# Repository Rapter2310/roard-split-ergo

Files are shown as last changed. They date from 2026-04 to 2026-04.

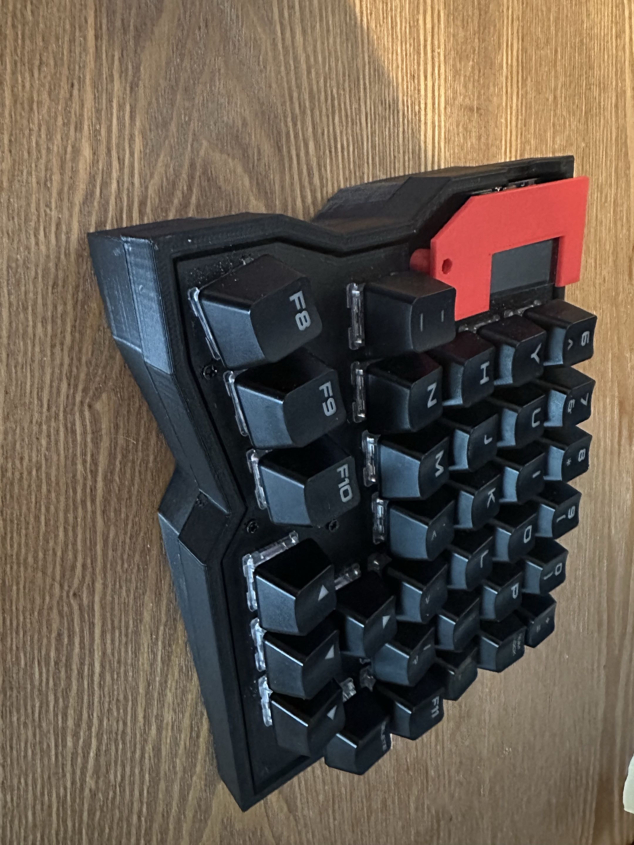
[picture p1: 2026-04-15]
docs/images/right_angle.jpg

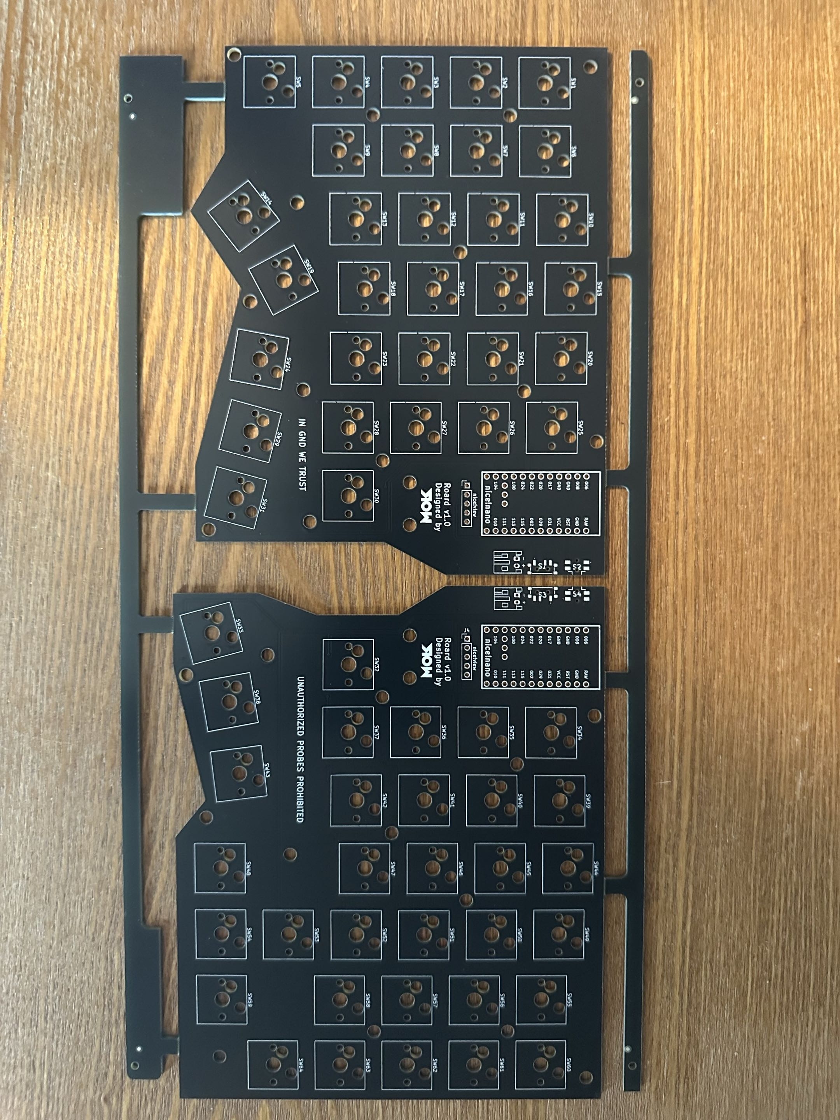
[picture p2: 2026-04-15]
docs/images/pcb_top.jpg

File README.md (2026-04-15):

# Roard Keyboard

Roard is a custom wireless split keyboard I designed, heavily based on the Lily58. The main physical difference is the layout. I modified it to include a dedicated arrow key cluster on the right half. 

The biggest technical difference is the wireless setup. Instead of standard Bluetooth, I'm using a 3-node Nordic Enhanced ShockBurst (ESB) configuration. The left and right halves connect to a third nice!nano plugged into the PC acting as a dedicated dongle, which fixes the latency and connection drops you sometimes get with standard BLE splits.

## Hardware Details
* **Controllers:** 3x nice!nano v2 (left, right, and central dongle).
* **Displays:** 2x nice!view screens.
* **Switches & Sockets:** Gateron Aliaz (silent tactiles) seated in Kailh MX hotswap sockets.
* **Power:** 3.7v 110mAh LiPo batteries.
* **Components & Assembly:** Sourced all the board-level SMD components (diodes, power/reset switches, battery connectors, and sockets) directly from Typeractive, and assembled the board using Kester solder wire.
* **Design Tools:** The core layout was built in Keyboard Layout Editor (KLE). I initially used the ai03 plate generator for rapid prototyping to test different angles and ergonomics before committing to the board design. To map the final physical matrix to the firmware, I used the [ZMK Physical Layout Converter](https://zmk-physical-layout-converter.streamlit.app/) to translate the KLE JSON directly into ZMK layout macros. The raw design files are in the `/design` folder.
* **PCB:** Custom routed in KiCad. Once the routing and standoff placements were finalized, I exported the board as a STEP file to serve as the foundation for the mechanical design.

## Case & Mechanical
I modeled the enclosure from scratch in Onshape. To guarantee perfect switch alignment and mounting hole clearance, I imported the KiCad STEP file directly into my Onshape workspace and traced the final switch plates and case standoffs around the exact geometry of the PCB.

I used a few different materials for the 3D printed parts depending on what they needed to do:
* **Case & Switch Plate:** PETG for general strength.
* **Tenting Kit:** TPU so it actually grips the desk and dampens the sound a bit.
* **Display Covers:** PLA to protect the nice!view screens.
Everything is held together with standard brass standoffs.

## Current Status & WIP
The board is fully functional as my daily driver, but I'm currently working on two main things:

1. **Customizing the nice!view Screens:** Switching from standard BLE to the ESB dongle setup breaks the standard `nice!view` widget implementation, which relies on BLE Zephyr services to report full connection states. Currently, the screens are running a basic fallback ZMK display profile that only outputs battery levels. I am actively rewriting the display logic to pull layer information and connection states over the ESB protocol to restore full functionality.
2. **Custom Keycaps:** I'm in the process of generating and 3D printing a custom keycap profile using [PseudoMakeMeKeyCapProfiles](https://github.com/pseudoku/PseudoMakeMeKeyCapProfiles).

## Repository Structure
* `/design`: KLE json files and prototyping assets.
* `/docs`: Photos of the finished board, the PCB, and the tenting kit.
* `/firmware`: ZMK config files, custom shield definitions, and ESB dongle setup.
* `/hardware`: KiCad project files, schematics, and production-ready Gerbers.
* `/mechanical`: STLs for 3D printing and STEP files exported from Onshape.

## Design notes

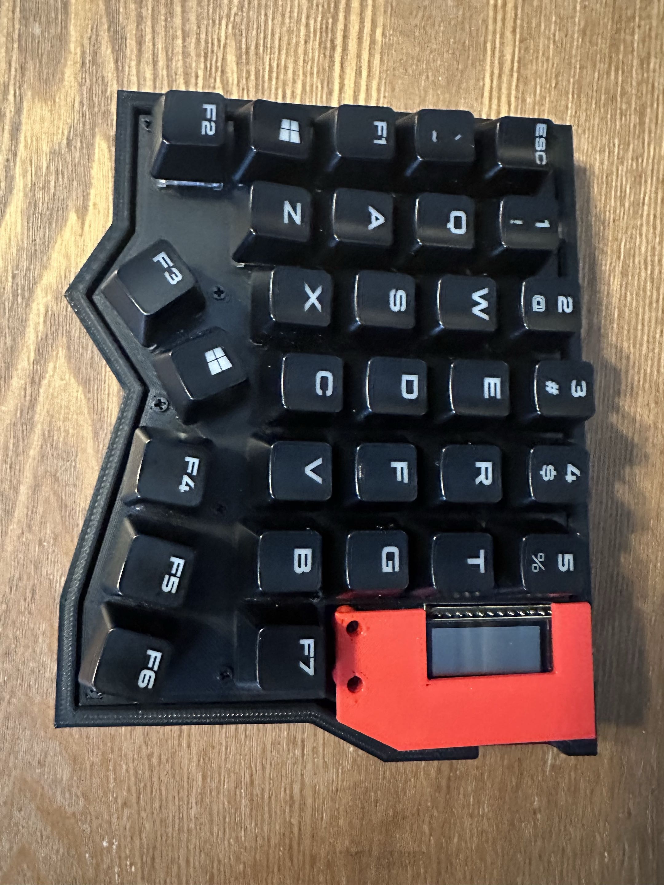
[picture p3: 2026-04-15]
docs/images/left_top.jpg

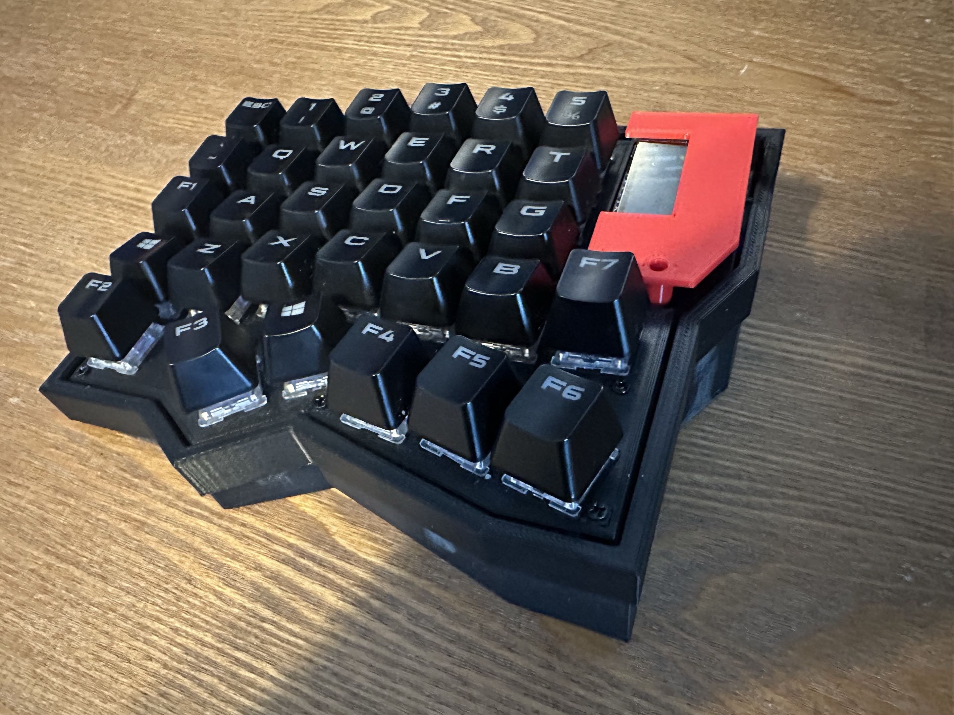
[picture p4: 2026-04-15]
docs/images/left_angle.jpg

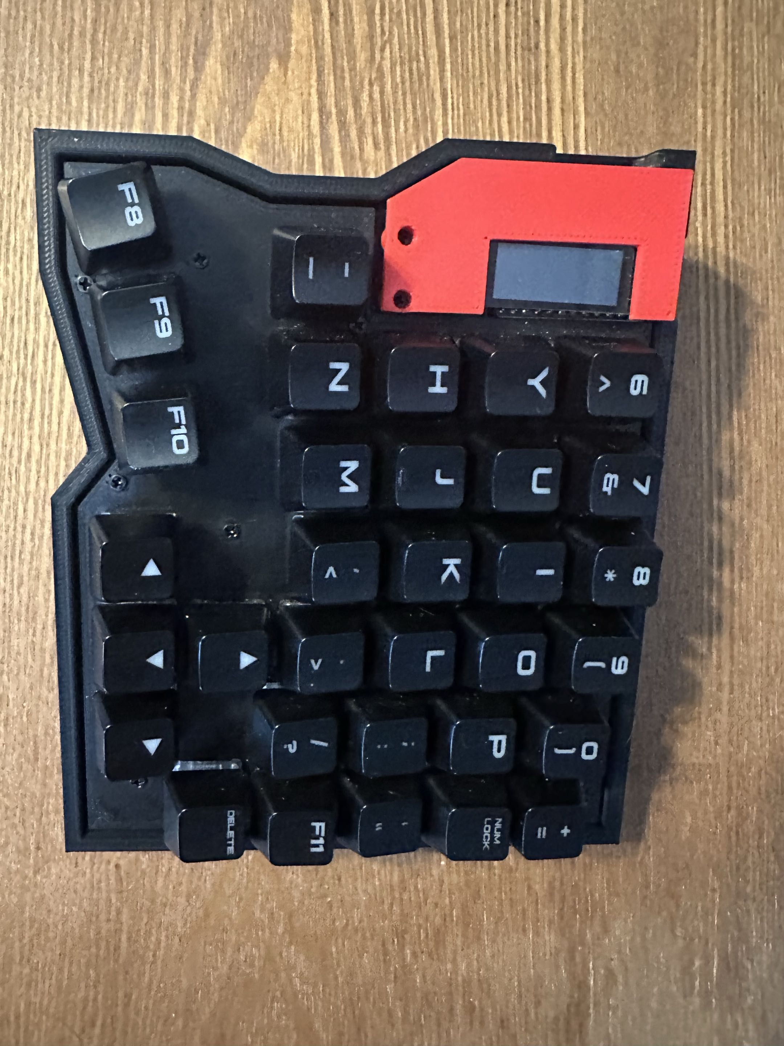
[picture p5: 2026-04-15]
docs/images/right_top.jpg

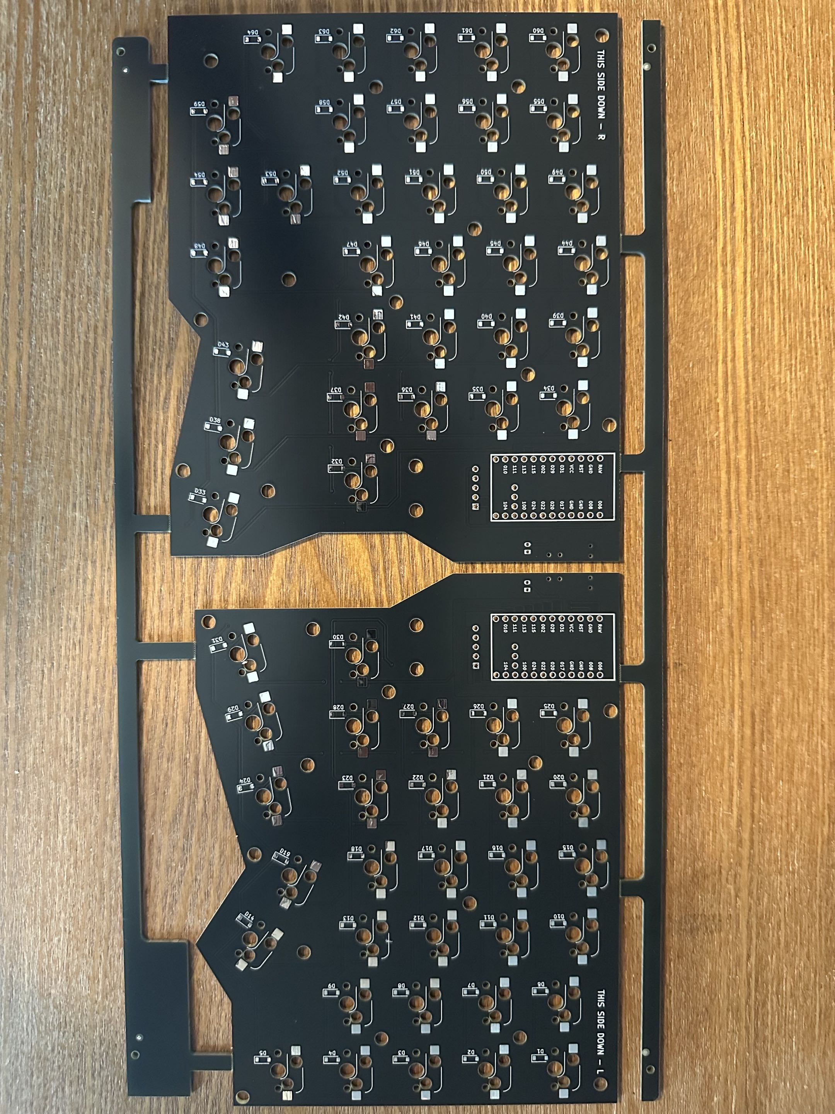
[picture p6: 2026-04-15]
docs/images/pcb_bottom.jpg

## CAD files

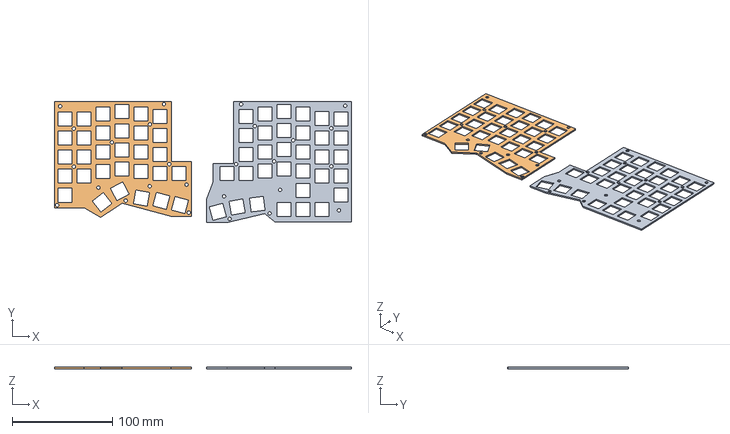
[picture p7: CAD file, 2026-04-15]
mechanical/step/plates.step
296.7 x 121.1 x 1.51 mm
plate_PCB_1
plate_PCB_2

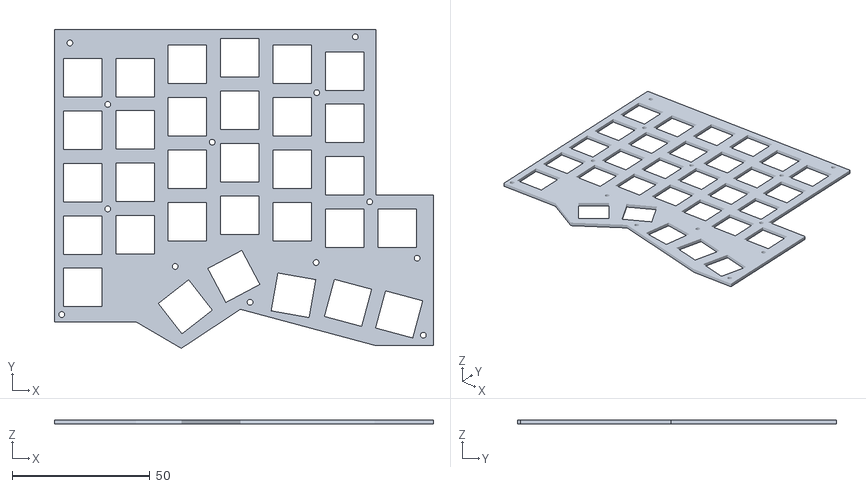
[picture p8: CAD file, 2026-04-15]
mechanical/stl/left_plate.stl
137.8 x 115.9 x 1.60

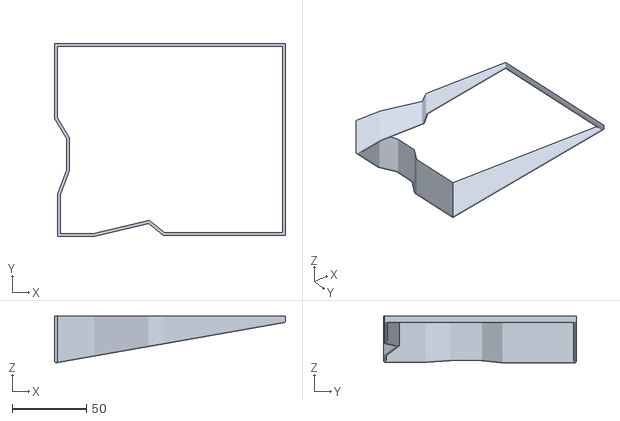
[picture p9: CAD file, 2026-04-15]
mechanical/stl/right_tent.stl
155.1 x 129.4 x 31.4

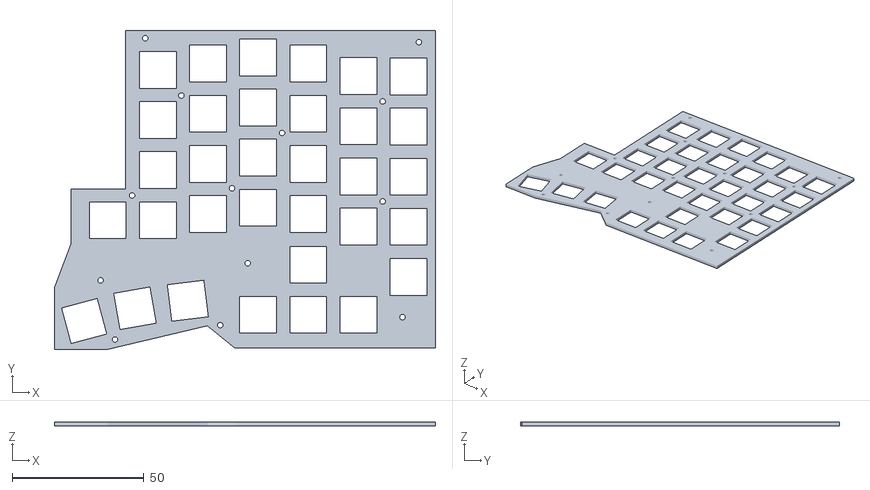
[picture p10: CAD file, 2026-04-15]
mechanical/stl/right_plate.stl
144.8 x 121.1 x 1.60

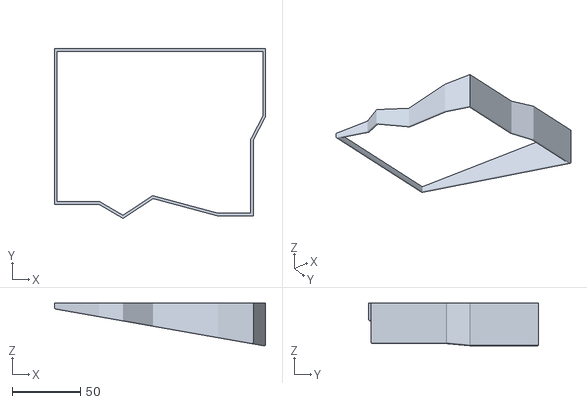
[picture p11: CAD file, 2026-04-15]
mechanical/stl/left_tent.stl
155.1 x 124.9 x 31.4

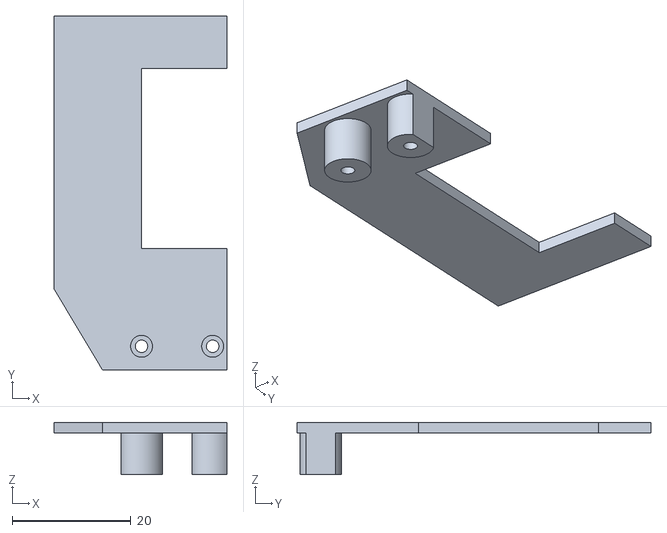
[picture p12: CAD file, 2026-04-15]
mechanical/stl/right_screen_cover.stl
29.2 x 59.7 x 8.80

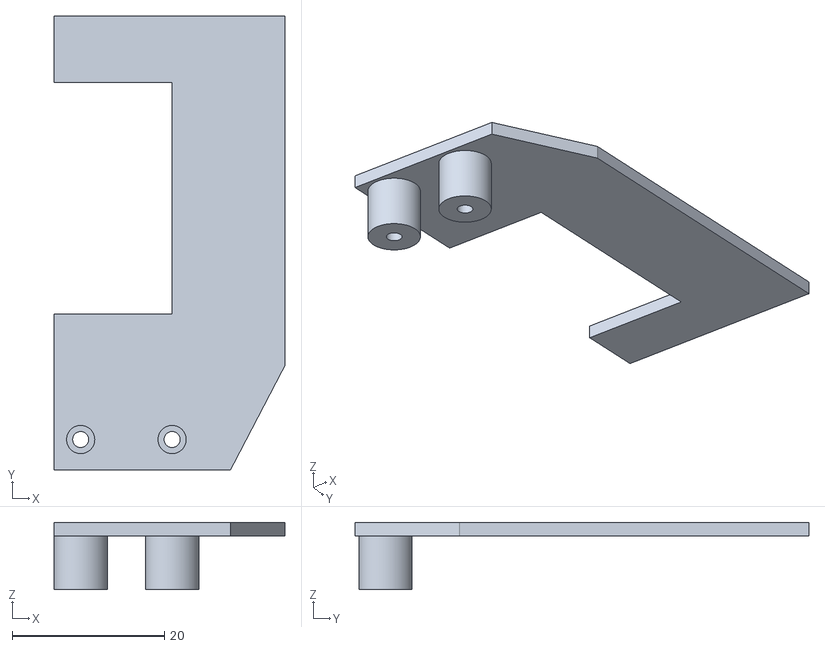
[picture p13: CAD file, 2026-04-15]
mechanical/stl/left_screen_cover.stl
30.3 x 59.6 x 8.80

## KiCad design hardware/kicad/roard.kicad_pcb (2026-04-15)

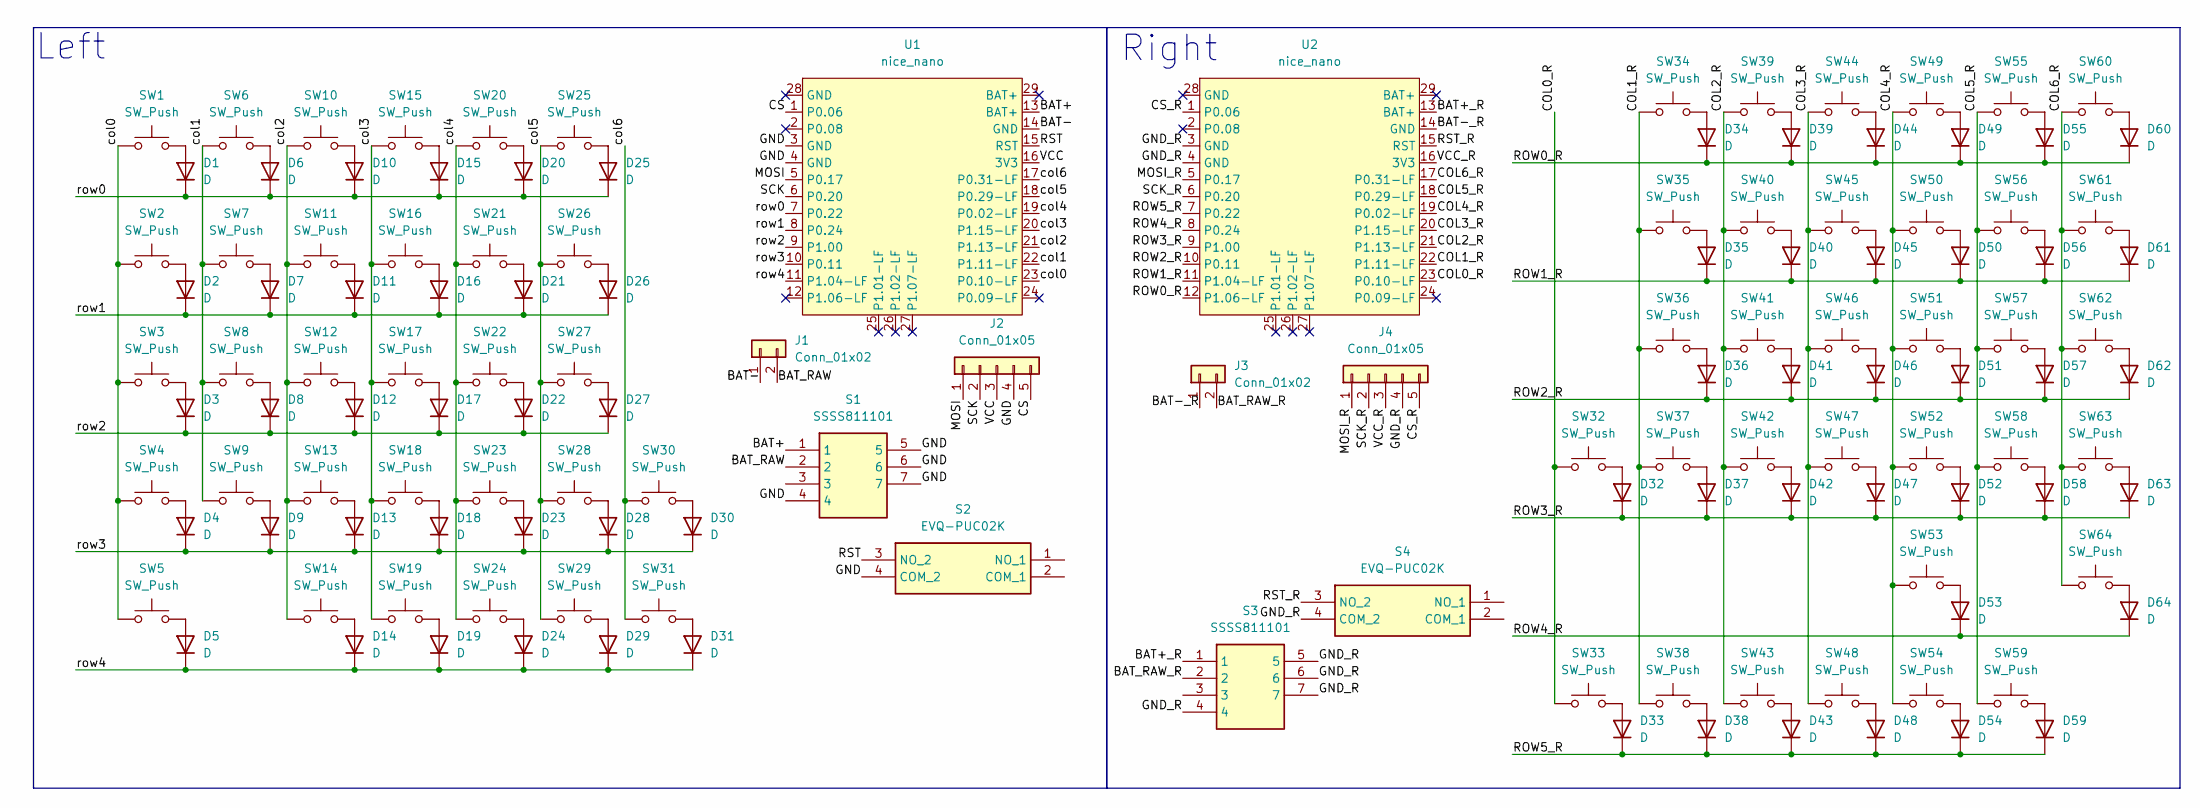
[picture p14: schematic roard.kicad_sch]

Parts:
D1, D2, D3, D4, D5, D6, D7, D8, D9, D10, D11, D12, D13, D14, D15, D16, D17, D18, D19, D20, D21, D22, D23, D24, D25, D26, D27, D28, D29, D30, D31, D32, D33, D34, D35, D36, D37, D38, D39, D40, D41, D42, D43, D44, D45, D46, D47, D48, D49, D50, D51, D52, D53, D54, D55, D56, D57, D58, D59, D60, D61, D62, D63, D64: D; D_SOD-123
J1, J3: Conn_01x02; JST_PH_S2B-PH-K_1x02_P2.00mm_Horizontal
J2, J4: Conn_01x05; PinHeader_1x05_P2.54mm_Vertical
S1, S3: SSSS811101; Mouser Part Number 688-SSSS811101
S2, S4: EVQ-PUC02K; EVQPUC02K; Mouser Part Number 667-EVQ-PUC02K
SW1, SW2, SW3, SW4, SW5, SW6, SW7, SW8, SW9, SW10, SW11, SW12, SW13, SW14, SW15, SW16, SW17, SW18, SW19, SW20, SW21, SW22, SW23, SW24, SW25, SW26, SW27, SW28, SW29, SW30, SW31, SW32, SW33, SW34, SW35, SW36, SW37, SW38, SW39, SW40, SW41, SW42, SW43, SW44, SW45, SW46, SW47, SW48, SW49, SW50, SW51, SW52, SW53, SW54, SW55, SW56, SW57, SW58, SW59, SW60, SW61, SW62, SW63, SW64: SW_Push; SW_Hotswap_Kailh_MX
U1, U2: nice_nano; nice_nano_pinChange

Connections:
/BAT+: S1.1, U1.13 (BAT+)
/BAT+_R: S3.1, U2.13 (BAT+)
/BAT-: J1.1, U1.14 (GND)
/BAT-_R: J3.1, U2.14 (GND)
/BAT_RAW: J1.2, S1.2
/BAT_RAW_R: J3.2, S3.2
/COL0_R: SW32.1, SW33.1, U2.23 (P0.10-LF)
/COL1_R: SW34.1, SW35.1, SW36.1, SW37.1, SW38.1, U2.22 (P1.11-LF)
/COL2_R: SW39.1, SW40.1, SW41.1, SW42.1, SW43.1, U2.21 (P1.13-LF)
/COL3_R: SW44.1, SW45.1, SW46.1, SW47.1, SW48.1, U2.20 (P1.15-LF)
/COL4_R: SW49.1, SW50.1, SW51.1, SW52.1, SW53.1, SW54.1, U2.19 (P0.02-LF)
/COL5_R: SW55.1, SW56.1, SW57.1, SW58.1, SW59.1, U2.18 (P0.29-LF)
/COL6_R: SW60.1, SW61.1, SW62.1, SW63.1, SW64.1, U2.17 (P0.31-LF)
/CS: J2.5, U1.1 (P0.06)
/CS_R: J4.5, U2.1 (P0.06)
/GND: J2.4, S1.4, S1.5, S1.6, S1.7, S2.4 (COM_2), U1.3 (GND), U1.4 (GND)
/GND_R: J4.4, S3.4, S3.5, S3.6, S3.7, S4.4 (COM_2), U2.3 (GND), U2.4 (GND)
/MOSI: J2.1, U1.5 (P0.17)
/MOSI_R: J4.1, U2.5 (P0.17)
/ROW0_R: D34.1 (K), D39.1 (K), D44.1 (K), D49.1 (K), D55.1 (K), D60.1 (K), U2.12 (P1.06-LF)
/ROW1_R: D35.1 (K), D40.1 (K), D45.1 (K), D50.1 (K), D56.1 (K), D61.1 (K), U2.11 (P1.04-LF)
/ROW2_R: D36.1 (K), D41.1 (K), D46.1 (K), D51.1 (K), D57.1 (K), D62.1 (K), U2.10 (P0.11)
/ROW3_R: D32.1 (K), D37.1 (K), D42.1 (K), D47.1 (K), D52.1 (K), D58.1 (K), D63.1 (K), U2.9 (P1.00)
/ROW4_R: D53.1 (K), D64.1 (K), U2.8 (P0.24)
/ROW5_R: D33.1 (K), D38.1 (K), D43.1 (K), D48.1 (K), D54.1 (K), D59.1 (K), U2.7 (P0.22)
/RST: S2.3 (NO_2), U1.15 (RST)
/RST_R: S4.3 (NO_2), U2.15 (RST)
/SCK: J2.2, U1.6 (P0.20)
/SCK_R: J4.2, U2.6 (P0.20)
/VCC: J2.3, U1.16 (3V3)
/VCC_R: J4.3, U2.16 (3V3)
/col0: SW1.1, SW2.1, SW3.1, SW4.1, SW5.1, U1.23 (P0.10-LF)
/col1: SW6.1, SW7.1, SW8.1, SW9.1, U1.22 (P1.11-LF)
/col2: SW10.1, SW11.1, SW12.1, SW13.1, SW14.1, U1.21 (P1.13-LF)
/col3: SW15.1, SW16.1, SW17.1, SW18.1, SW19.1, U1.20 (P1.15-LF)
/col4: SW20.1, SW21.1, SW22.1, SW23.1, SW24.1, U1.19 (P0.02-LF)
/col5: SW25.1, SW26.1, SW27.1, SW28.1, SW29.1, U1.18 (P0.29-LF)
/col6: SW30.1, SW31.1, U1.17 (P0.31-LF)
/row0: D1.1 (K), D6.1 (K), D10.1 (K), D15.1 (K), D20.1 (K), D25.1 (K), U1.7 (P0.22)
/row1: D2.1 (K), D7.1 (K), D11.1 (K), D16.1 (K), D21.1 (K), D26.1 (K), U1.8 (P0.24)
/row2: D3.1 (K), D8.1 (K), D12.1 (K), D17.1 (K), D22.1 (K), D27.1 (K), U1.9 (P1.00)
/row3: D4.1 (K), D9.1 (K), D13.1 (K), D18.1 (K), D23.1 (K), D28.1 (K), D30.1 (K), U1.10 (P0.11)
/row4: D5.1 (K), D14.1 (K), D19.1 (K), D24.1 (K), D29.1 (K), D31.1 (K), U1.11 (P1.04-LF)
unnamed: D1.2 (A), SW1.2
unnamed: D2.2 (A), SW2.2
unnamed: D3.2 (A), SW3.2
unnamed: D4.2 (A), SW4.2
unnamed: D5.2 (A), SW5.2
unnamed: D6.2 (A), SW6.2
unnamed: D7.2 (A), SW7.2
unnamed: D8.2 (A), SW8.2
unnamed: D9.2 (A), SW9.2
unnamed: D10.2 (A), SW10.2
unnamed: D11.2 (A), SW11.2
unnamed: D12.2 (A), SW12.2
unnamed: D13.2 (A), SW13.2
unnamed: D14.2 (A), SW14.2
unnamed: D15.2 (A), SW15.2
unnamed: D16.2 (A), SW16.2
unnamed: D17.2 (A), SW17.2
unnamed: D18.2 (A), SW18.2
unnamed: D19.2 (A), SW19.2
unnamed: D20.2 (A), SW20.2
unnamed: D21.2 (A), SW21.2
unnamed: D22.2 (A), SW22.2
unnamed: D23.2 (A), SW23.2
unnamed: D24.2 (A), SW24.2
unnamed: D25.2 (A), SW25.2
unnamed: D26.2 (A), SW26.2
unnamed: D27.2 (A), SW27.2
unnamed: D28.2 (A), SW28.2
unnamed: D29.2 (A), SW29.2
unnamed: D30.2 (A), SW30.2
unnamed: D31.2 (A), SW31.2
unnamed: D32.2 (A), SW32.2
unnamed: D33.2 (A), SW33.2
unnamed: D34.2 (A), SW34.2
unnamed: D35.2 (A), SW35.2
unnamed: D36.2 (A), SW36.2
unnamed: D37.2 (A), SW37.2
unnamed: D38.2 (A), SW38.2
unnamed: D39.2 (A), SW39.2
unnamed: D40.2 (A), SW40.2
unnamed: D41.2 (A), SW41.2
unnamed: D42.2 (A), SW42.2
unnamed: D43.2 (A), SW43.2
unnamed: D44.2 (A), SW44.2
unnamed: D45.2 (A), SW45.2
unnamed: D46.2 (A), SW46.2
unnamed: D47.2 (A), SW47.2
unnamed: D48.2 (A), SW48.2
unnamed: D49.2 (A), SW49.2
unnamed: D50.2 (A), SW50.2
unnamed: D51.2 (A), SW51.2
unnamed: D52.2 (A), SW52.2
unnamed: D53.2 (A), SW53.2
unnamed: D54.2 (A), SW54.2
unnamed: D55.2 (A), SW55.2
unnamed: D56.2 (A), SW56.2
unnamed: D57.2 (A), SW57.2
unnamed: D58.2 (A), SW58.2
unnamed: D59.2 (A), SW59.2
unnamed: D60.2 (A), SW60.2
unnamed: D61.2 (A), SW61.2
unnamed: D62.2 (A), SW62.2
unnamed: D63.2 (A), SW63.2
unnamed: D64.2 (A), SW64.2

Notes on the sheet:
Right
Left

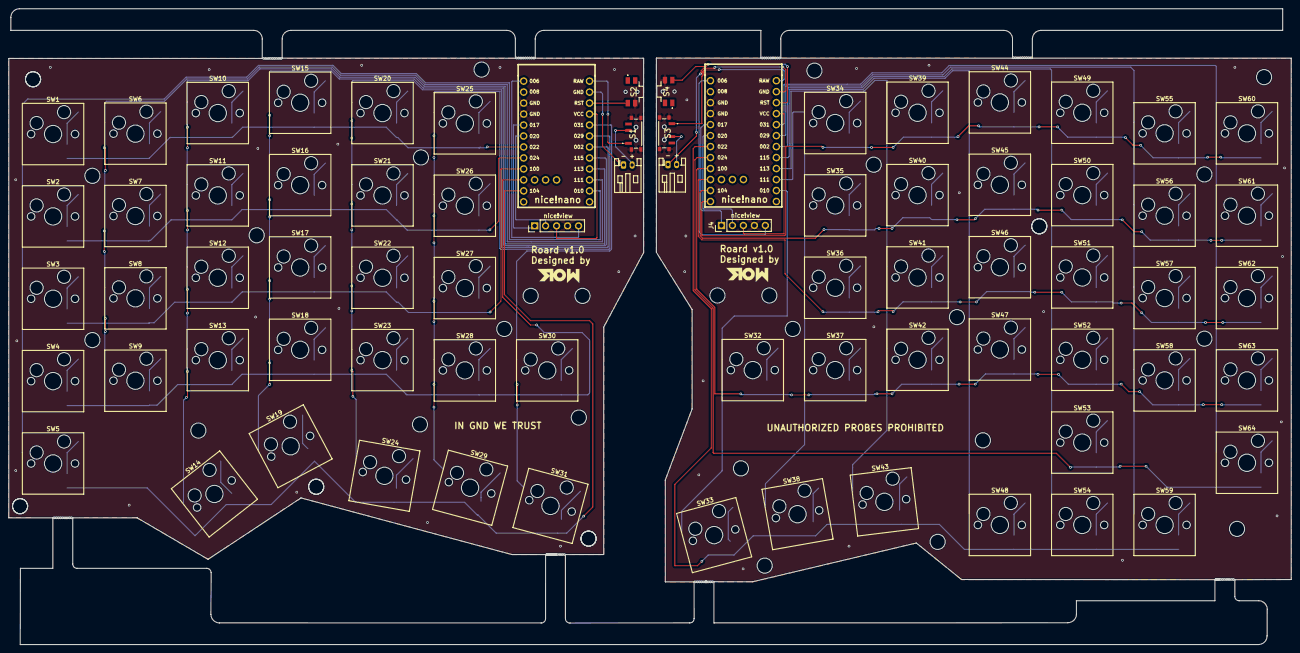
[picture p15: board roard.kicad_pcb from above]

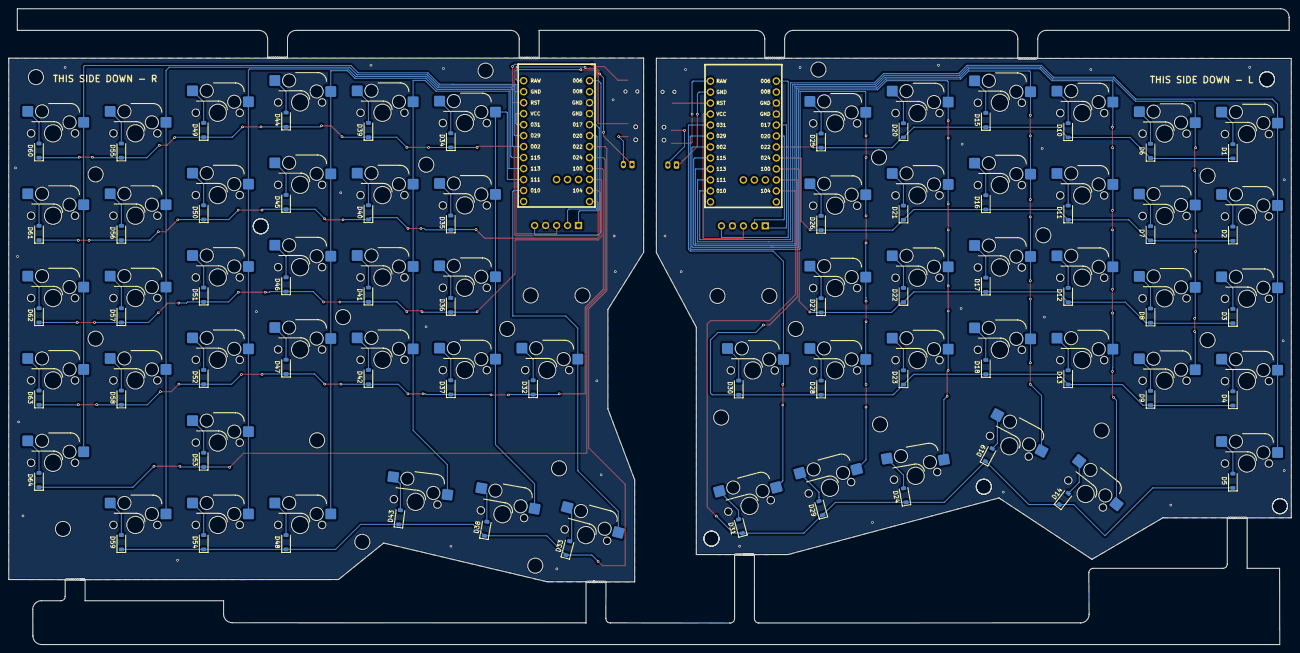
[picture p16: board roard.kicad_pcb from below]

Board: 2 copper layers, 296.7 x 147.1 mm, 140 parts (64 on the bottom side), 107 nets.

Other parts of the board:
H4, H15: tab; breakaway04

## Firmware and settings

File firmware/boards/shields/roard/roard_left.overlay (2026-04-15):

#include "roard.dtsi"

&kscan {
    row-gpios =
          <&gpio0 22 (GPIO_ACTIVE_HIGH | GPIO_PULL_DOWN)>  /* row0: P0.22 */
        , <&gpio0 24 (GPIO_ACTIVE_HIGH | GPIO_PULL_DOWN)>  /* row1: P0.24 */
        , <&gpio1 0  (GPIO_ACTIVE_HIGH | GPIO_PULL_DOWN)>  /* row2: P1.00 */
        , <&gpio0 11 (GPIO_ACTIVE_HIGH | GPIO_PULL_DOWN)>  /* row3: P0.11 */
        , <&gpio1 4  (GPIO_ACTIVE_HIGH | GPIO_PULL_DOWN)>  /* row4: P1.04 */
        ;

    col-gpios =
          <&gpio0 10 GPIO_ACTIVE_HIGH> /* col0: P0.10 */
        , <&gpio1 11 GPIO_ACTIVE_HIGH> /* col1: P1.11 */
        , <&gpio1 13 GPIO_ACTIVE_HIGH> /* col2: P1.13 */
        , <&gpio1 15 GPIO_ACTIVE_HIGH> /* col3: P1.15 */
        , <&gpio0 2  GPIO_ACTIVE_HIGH> /* col4: P0.02 */
        , <&gpio0 29 GPIO_ACTIVE_HIGH> /* col5: P0.29 */
        , <&gpio0 31 GPIO_ACTIVE_HIGH> /* col6: P0.31 */
        ;
};

/ {
    esb_split {
        compatible = "zmk,esb-split";
        base-addr-0 = <0xE7 0xF1 0xB3 0x4C>;
        base-addr-1 = <0xC2 0x3D 0xA7 0x7B>;
        addr-prefix = <0xE7 0xC2 0x3C 0xC4 0x5D 0xA9 0xF5 0xC8>;
    };
};
